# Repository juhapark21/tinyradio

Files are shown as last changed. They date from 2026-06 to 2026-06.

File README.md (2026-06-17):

# Tiny radio keychain!!

A keychain that is also a working fm radio:D
Screenshot 2026-06-17 at 6 27 37 AM
Screenshot 2026-06-17 at 6 27 50 AM
Screenshot 2026-06-17 at 6 28 07 AM 

## Specifications 
- XIAO RP2040 microcontroller - edit firmware without any extra equipment 
- RDA5807M - cheap and widely available FM radio chip
- Wired earphones act as an antenna for the radio
- Runs on a CR3032 coin cell battery
- 58 x 42.4mm (can be made even smaller if you don't want mounting holes)
- bom can be found as bom.csv 

## Usage 
- Provide a battery and wired earphones.
- To flash the firmware, follow [these instructions](https://wiki.seeedstudio.com/XIAO-RP2040-with-Arduino/). 
- Press the left knob down to turn on/off.
- Turn the left knob to adjust volume.
- Turn the right knob to adjust frequency.
- Adjust the earphone wire position and length to adjust reception of signals. 

## Why 
I made it because I like tiny things (my most prized pencilcase posession is a tiny calculator), I like keychains, and I like radios. I'm also new to hardware stuff so it was nice to get started with a simpler receiver. That, and I had impulse-bought RDA5807 chips a year or so ago.
I also wanted a neat trinket I could give to radio people when I meet them at conventions and stuff. 
Additionally, my current radio is rather large... so I can't really carry it around anywhere. 

## Process 
The development process is logged in detail [here](https://stasis.hackclub.com/dashboard/projects/cmndil887006o01qo4aqrqvzn) and later [here](https://fallout.hackclub.com/projects/3242). It took me quite a while (~1 1/2 month of consistent work) because I was pretty much new to PCB design. I learned a lot about KiCad and the design process through this project.

## Next steps 
I want to try making multiple at a time (larger scale) so that I have enough to go around. Also, harder projects (tiny calculator...). 

## Zine 
zine - tinyradio

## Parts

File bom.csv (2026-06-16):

Index | MPN | Manufacturer | Package | Description | RoHS | Quantity | MOQ | Multiple | Unit Price($) | Extended Price($) | Product Link
1 | CR2032-BS-6-1 | QIJEY | - | Battery Holder Coin CR2032 Cell SMD | yes | 5 | 5 | 5 | 0.1380 | 0.69 | https://www.lcsc.com/product-detail/C70377.html
2 | KF106M025C05RR0VH2FP0 | Chengx | Through Hole,D4xL5mm | 10uF 25V Aluminum Electrolytic Capacitors Through Hole,D4xL5mm 1000hrs@105℃ | yes | 50 | 50 | 50 | 0.0099 | 0.50 | https://www.lcsc.com/product-detail/C43846.html
3 | 1206B104K500CT | Walsin | 1206 | 100nF ±10% 50V Ceramic Capacitor X7R 1206 | yes | 10 | 10 | 10 | 0.0135 | 0.14 | https://www.lcsc.com/product-detail/C93194.html
4 | TCC1206COG101J101DT | CCTC | 1206 | 100pF ±5% 100V Ceramic Capacitor C0G 1206 | yes | 50 | 50 | 50 | 0.0116 | 0.58 | https://www.lcsc.com/product-detail/C5448997.html
5 | PJ-320B | BOOMELE(Boom Precision Elec) | SMD | 3.5mm Headphone Jack 200mA 30V Surface Mount | yes | 10 | 10 | 10 | 0.0627 | 0.63 | https://www.lcsc.com/product-detail/C18594.html
6 | 1206W4F4701T5E | UNI-ROYAL | 1206 | 4.7kΩ ±1% 250mW 1206 Thick Film Resistor | yes | 100 | 100 | 100 | 0.0060 | 0.60 | https://www.lcsc.com/product-detail/C17936.html
7 | EC11E1534441 | ALPSALPINE | Through Hole | 10mA -40℃~+85℃ Through Hole DIP Switches/SIP Switches RoHS | yes | 5 | 1 | 1 | 0.7406 | 3.70 | https://www.lcsc.com/product-detail/C2687287.html
8 | RK09K11300DR | ALPSALPINE | Through Hole | ±20% 50mW 10kΩ Through Hole Rotary Potentiometers, Rheostats RoHS | yes | 5 | 1 | 1 | 0.7849 | 3.92 | https://www.lcsc.com/product-detail/C3020615.html
9 | LQW18ANR27J00D | muRata | 0603 | 110mA 270nH ±5% 3.4Ω Unshielded Inductor 0603 Fixed Inductors RoHS | yes | 20 | 20 | 20 | 0.0381 | 0.76 | https://www.lcsc.com/product-detail/C98093.html
10 | EC12D1524403 | ALPSALPINE | Through Hole | Through Hole Encoders RoHS | yes | 5 | 1 | 1 | 0.9614 | 4.81 | https://www.lcsc.com/product-detail/C112349.html
11 | 102010428 | Seeed Studio | SMD | Seeed Studio XIAO RP2040 Microcontroller, with Dual-Core ARM Cortex M0+ Processor | yes | 1 | 1 | 1 | 9.99 | 9.99 | https://a.co/d/0feymYab
12 | RDA5807 | RDA Microelectronics | SMD | 4pcs FM Stereo Radio Module RDA5807M Wireless Module RRD-102 V2.0 | yes | 4 | 4 | 1 | 2.25 | 8.99 | https://a.co/d/0geL9m36
Total price |  |  |  |  |  |  |  |  |  | 35.31

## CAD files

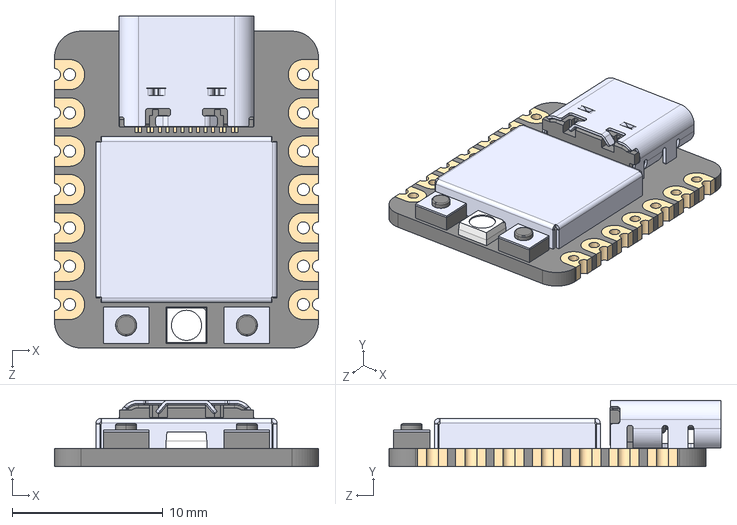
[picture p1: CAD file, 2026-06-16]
pcb/102010428--3DModel-STEP-269445.STEP
17.5 x 4.40 x 22.0 mm

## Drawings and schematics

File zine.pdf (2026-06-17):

# tiny radio

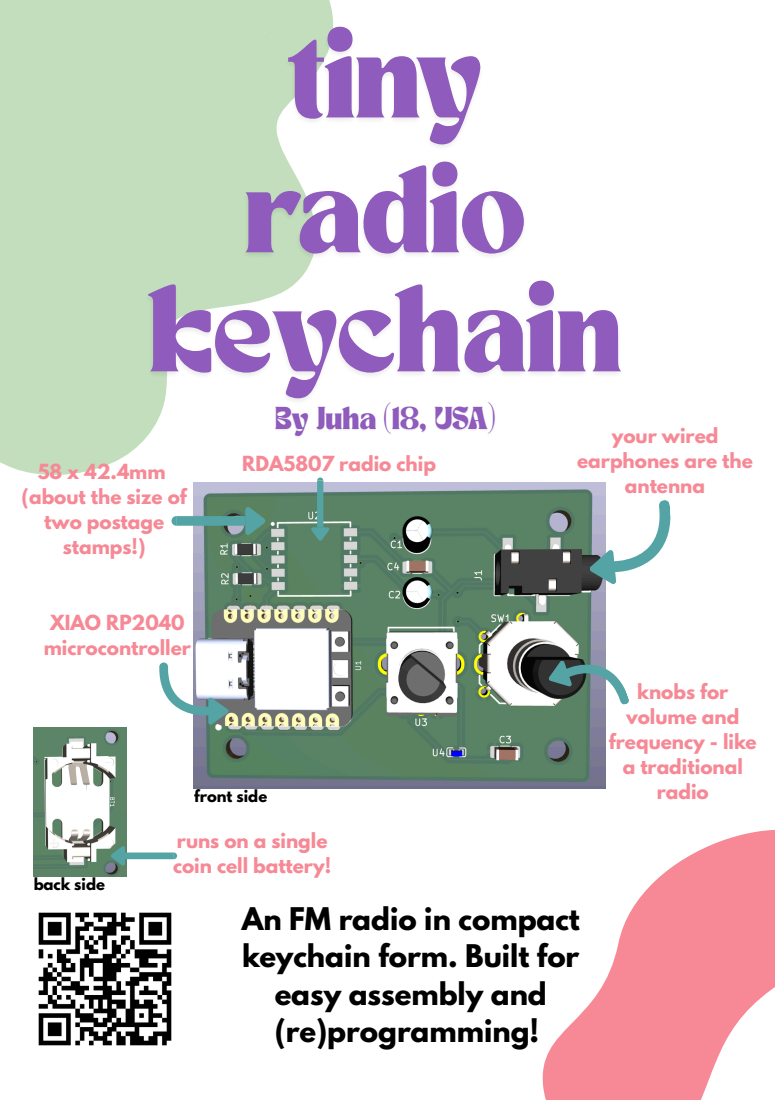
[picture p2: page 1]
keychain; radio keychain; XIAO RP2040 microcontroller; knobs for volume and frequency - like a traditional radio; RDA5807 radio chip; back side

By Juha (18, USA)

your wired
earphones are the
antenna

(about the size of
two postage
stamps!)

front side
runs on a single
coin cell battery!
An FM radio in compact
keychain form. Built for
easy assembly and
(re)programming!

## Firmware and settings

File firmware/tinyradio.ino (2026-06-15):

// https://pu2clr.github.io/RDA5807/extras/apidoc/html/modules.html 
// https://wiki.seeedstudio.com/XIAO-RP2040-with-Arduino/ 
// https://github.com/pu2clr/RDA5807/blob/master/examples/RDA5807_01_SERIAL_MONITOR/RDA5807_01_ALL_TEST_SERIAL_MONITOR/RDA5807_01_ALL_TEST_SERIAL_MONITOR.ino 
// https://www.youtube.com/watch?v=X4Lra0SWzw8 
#include <RDA5807.h> 

RDA5807 rx; 

const int potPin = A0; 
int prevVol; 

const int CLK = D1; 
const int DT = D2; 
int freq = 9030; 
int clockState; 
int lastClockState; 

int maxFreq; 
int minFreq; 

void setup() {

  pinMode(potPin, INPUT); 
  pinMode(CLK, INPUT);
  pinMode(DT, INPUT); 

  Serial.begin(9600); 

  lastClockState = digitalRead(CLK) 


  rx.setup(); 
  rx.setBand(0); // 87-108 MHz (US/Europe)
  //rx.setBand(2); // 76-108 MHz (worldwide) 
  maxFreq = rx.getMaximunFrequencyOfTheBand(); 
  minFreq = rx.getMinimumFrequencyOfTheBand(); 

  //rx.setVolume(6); // 0-15 
  // Set to whatever volume knob is set to  
  int vol = analogRead(potPin);
  vol = map(vol, 0, 4095, 0, 15); 
  rx.setVolume(vol);

  // Frequency you want to select in MHz multiplied by 100.
  rx.setFrequency(freq) // 90.3MHz - Classical California 
}

void loop() {
  // Volume control 
  int potVal = analogRead(potPin);
  // Scale to 0-15 - what setVolume() wants 
  int scaledPotVal = map(potVal, 0, 4095, 0, 15)
  // Only update volume if it actually changed (no need to set volume constantly?)
  if (scaledPotVal != prevVol) {
    rx.setVolume(scaledPotVal)
  }
  prevVol = scaledPotVal; 

  // Frequency control 
  clockState = digitalRead(CLK); 
  if (clockState != lastClockState) 
  {
    if (digitalRead(DT) != clockState) 
    {
      // Increment 
      if ((freq+1) <= maxFreq) 
      {
        freq++; 
      }
      rx.setFrequency(freq)
      //rx.setFrequencyUp(); 
    } else 
    {
      // Decrement 
      if ((freq-1) >= minFreq)
      {
        freq--; 
      }
      rx.setFrequency(freq)
      //rx.setFrequencyDown(); 
    }
    Serial.print("Position: ");
    Serial.println(freq) ;     
  }

  lastClockState = clockState; 
}

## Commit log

2026-05-12 Add current journal snapshot
2026-05-12 Add prod files
    [bom.csv, designators.csv, positions.csv]
2026-06-16 reorganize files and update pcb
    [102010428--3DModel-STEP-269445.STEP]
